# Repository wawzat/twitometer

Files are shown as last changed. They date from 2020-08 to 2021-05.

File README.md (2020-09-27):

# Twitometer  
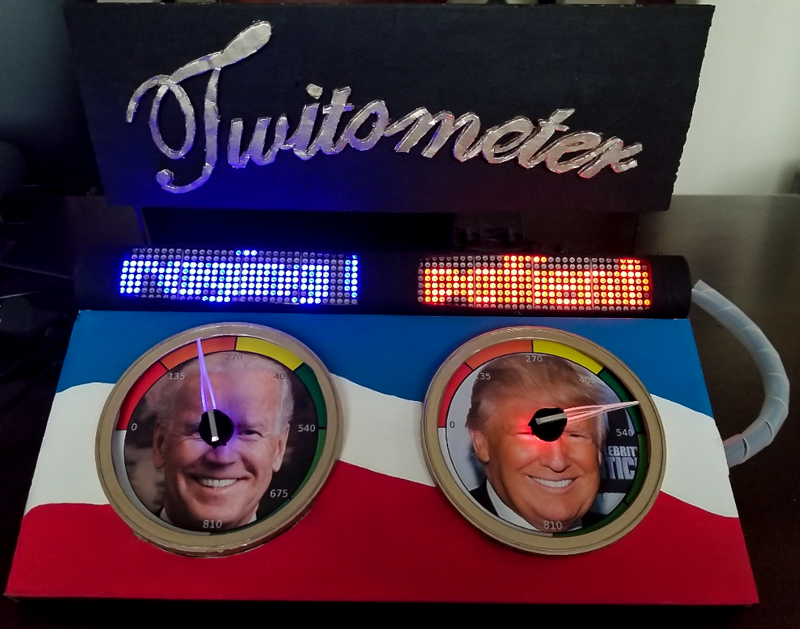
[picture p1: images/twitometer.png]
Twitometer


## Operation  
1. Displays Tweets and tweets per minute for US presidential candidates.
2. Raspberry Pi establishes a connection to Twitter Streaming API via Tweepy.  
3. Tweets are received that include text which matches a series of words ("Biden" "Trump").  
4. There are two Arduinos connected to the Pi via I2C. One for the LED Matrix displays and one for the two stepper motor gauges.
5. "Tweets per minute" is calculated and sent as bytes to the "stepper" Arduino via I2C.  
6. The Arduino then outputs a pulse for each microstep to a microstepping controller which is connected to two X27-168 instrumentation steppers which drive the gauge needles.  
7. Periodically the text of a tweet corresponding to a keyword (Biden or Trump) is sent to the "display" Arduino via I2C.  
8. The display Arduino sends the text over I2C to one of two corresponding MAX7219 8x32 LED matrices (blue for Biden, red for Trump).  
9. The corresponding tweet scrolls across each display.  

## Future improvements   
1. Attempt to classify tweets as "positive" or "negative" by comparison to lists of "positive" or "negative" words doesn't work very well. As a result, due to the nature of Twitter, the gauges might be best thought of as negative attention meters.   
2. Leftover unused variables and code fragments need to be cleaned up.  
3. I2C communications would benefit from more robust error checking and flow control. Periodic I2C errors exist.  
4. Scrolling text sometimes appears to be garbled or truncated.  
5. If too many I2C errors occur in succession, the Pi brute force reboots the Arduinos by cycling the power.  
6. Basic de-amateurization of the code.  

 ## Parts List
1. 1 x Raspberry Pi Model 3B+ w/ SD Card
2. 1 x USB power supply for Raspberry Pi
3. 2 x Arduino Pro Mini 5V/16Mhz
4. 1 x SparkFun DC/DC Converter Breakout (BOB-09370)
5. 1 x 1/2 Watt  1.3K ohm Carbon Comp Resistor
6. 1 x 1/2/4 SOP28 SSOP28 TSSOP28 to DIP28 0.7" Header Spacing SMD Adapter PCB Board
7. 1 x AX AX1201728SG SOP-28 Quad Microstepping Controller IC
8. 2 x X27-168 Stepper Motors
9. 1 x 2x uxcell Instrument Cluster Pointer Needle Set for HAVAL H2 (use small dia heat shrink on motor stems for friction fit)
10. 1 x DAOKI MAX7219 Dot led Matrix MCU 8x32 LED Display Module for Arduino, Blue
11. 1 x DAOKI MAX7219 Dot led Matrix MCU 8x32 LED Display Module for Arduino, Red
12. 1 x Red LED
13. 1 x 150 ohm resistor
14. 1 x Blue LED
15. 1 x 100 ohm resistor
16. Misc shrink tubing
17. Misc jumper wires
18. 1 x Adafruit Pi T-Cobbler Plus w/ ribbon cable
19. Spiral cable wrap
20. Coobl Dupont Jumper Wire Male Pin Connectors 2.54mm
21. 1 x BB400 Solderless Breadboard 
22. 1 x BB830 Solderless Breadboard

## Schematic Diagram  
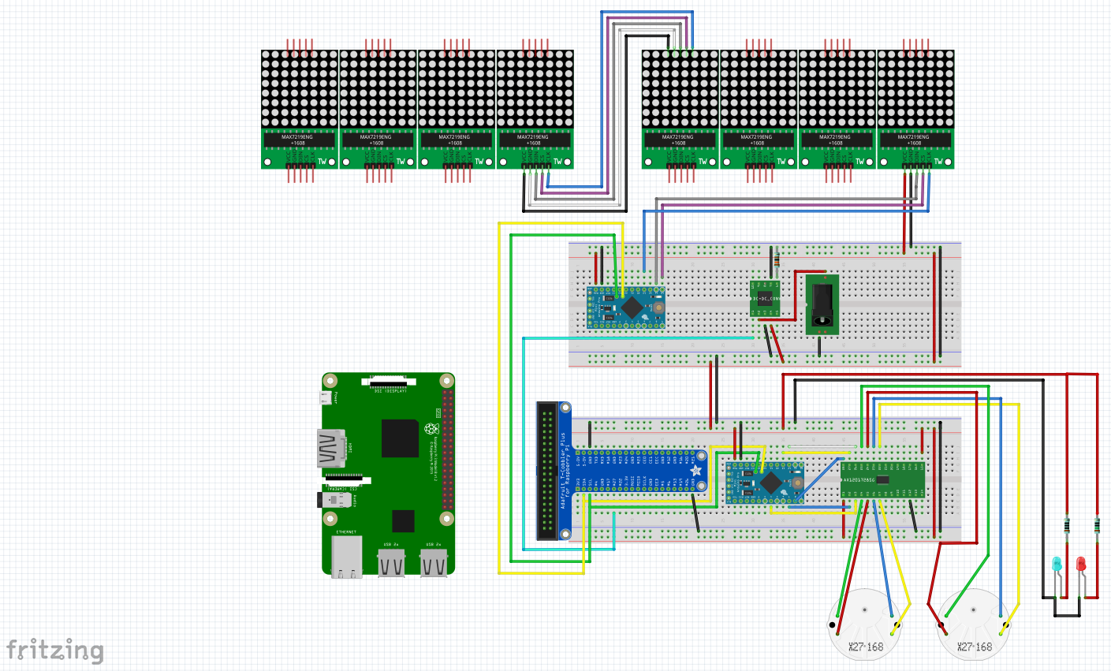
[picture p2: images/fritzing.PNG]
fritzing


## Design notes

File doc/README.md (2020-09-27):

Twitometer

Operation
Raspberry Pi establishes a Twitter Streaming API via Tweepy. 
Tweets are retrieved that include text that match a series of words (Biden Trump) 
"Tweets per minute" is calculated and sent to one of two Arduino's via I2C 
The Arduino outputs a pulse for each microstep to a microstepping controller which is connected to an X27-168 instrumentation stepper. 
Periodically  the text of a tweet corresponding to a keyword (Trump or Biden) is sent to the second Arduino via I2C. 
The second Arduino sends the text over I2C one of two corresponding MAX7219 8x32 LED matrices (blue for Biden, red for Trump). 
The corresponding tweet scrolls across each display. 

Future improvements
Naive attempt to classify tweets as "positive" or "negative" by comparison to lists of "positive" or "negative" words doesn't work very well. 
 
Left over unused variables and code fragments need to be cleaned up. 
 
I2C communications might benefit from more robust error checking and flow control. Periodic I2C errors still exist. 
 
Periodically scrolling text appears to be garbled or truncated.
 
If too many I2C errors occur in succession, the PI brute force reboots the Arduinos by cycling the power. 
 
Basic de-amateurization 

Schematic Diagram 
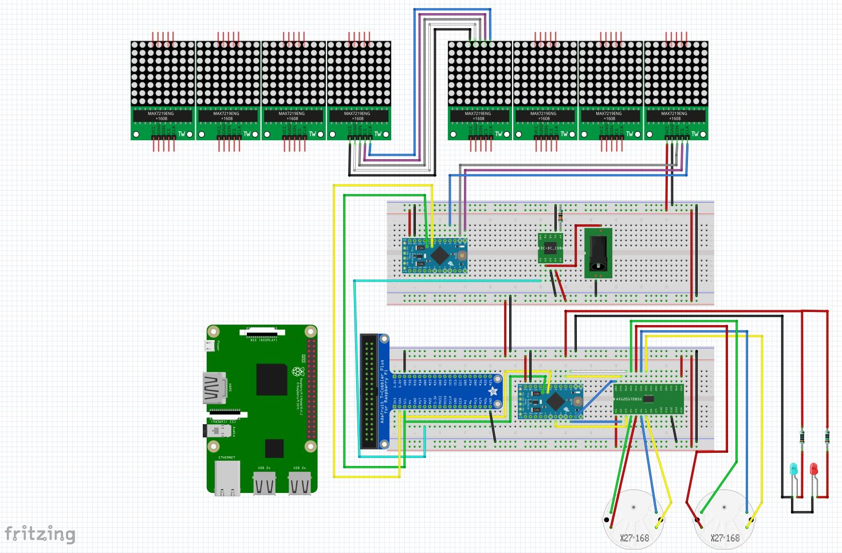
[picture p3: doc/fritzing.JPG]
fritzing


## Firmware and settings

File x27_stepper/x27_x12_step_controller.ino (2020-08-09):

//Receives bytes from Raspberry Pi in the format XYYYY where X is the motor number and YYYY is the desired motor position.
//YYYY is variable length from 1 to 3240 (270 Deg)
//James S. Lucas 20200726
#include <SwitecX12.h>
#include <Wire.h>
const int STEPS = 315 * 12;
const int A_STEP = 8;
const int A_DIR = 2;
const int B_STEP = 4;
const int B_DIR = 7;
const int RESET = 12;

SwitecX12 motor1(STEPS, A_STEP, A_DIR);
SwitecX12 motor2(STEPS, B_STEP, B_DIR);

//Arduino code to receive I2C communication from Raspberry Pi

// Define the I2C address of this device.
#define addr 0x08

void setup(void) {
  digitalWrite(RESET, HIGH);
  Serial.begin(9600);
  motor1.zero();
  motor2.zero();

  // begin running as an I2C slave on the specified address
  Wire.begin(addr);
 
  // create event for receiving data
  Wire.onReceive(receiveEvent);
}


//Global variables for position
int position1 = 0;
int position2 = 0;


// Function that executes whenever data is received from master
void receiveEvent(int howMany) {
  char cmd[16];
  char buffer[5];
  int motor_num;
  int char_pos = 0;
  while (Wire.available()) { // loop through all but the last
    char c = Wire.read(); // receive byte as a character
    cmd[char_pos] = (char)c;
    char_pos++;
    cmd[char_pos] = '\0';
  }
  char_pos = 0;


//Parse the command into motor number and position
  motor_num = cmd[0];
  buffer[0] = cmd[1];
  buffer[1] = cmd[2];
  buffer[2] = cmd[3];
  buffer[3] = cmd[4];
  buffer[4] = '\0';

  if (motor_num == 1) {
    position1 = atoi(buffer);
  }
  else if (motor_num == 2) {
    position2 = atoi(buffer);
  }
}


void loop(void) {
 
  motor1.setPosition(position1);
  motor2.setPosition(position2);

  motor1.update();
  motor2.update();
}

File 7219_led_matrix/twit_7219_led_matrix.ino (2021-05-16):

/* Example code for scrolling text effect on MAX7219 LED dot matrix display with Arduino. More info: https://www.makerguides.com */

// Include the required LED libraries:
#include <MD_Parola.h>
#include <MD_MAX72xx.h>
#include <SPI.h>

#include <Wire.h>

// Define hardware type, size, and output pins:
#define HARDWARE_TYPE MD_MAX72XX::FC16_HW
#define MAX_DEVICES 8
#define num_zones 2
#define CS_PIN 10

// Create a new instance of the MD_Parola class with hardware SPI connection:
MD_Parola myDisplay = MD_Parola(HARDWARE_TYPE, CS_PIN, MAX_DEVICES);

// Define the I2C address of this device for receiving data from Raspberry Pi
#define addr 0x06

char msg[290];
char msg_0[290];
char msg_1[290];
int char_pos = 0;
int block_count = 0;
int block_flag = 0;

void setup() {
  Serial.begin(9600);
  // begin running as an I2C slave on the specified address
  Wire.begin(addr);
 
  // create event for receiving data
  Wire.onReceive(receiveEvent);

  // Intialize the LED object:
  myDisplay.begin(num_zones);
  //myDisplay.begin();

  // Setup display zones
  myDisplay.setZone(0, 0, 3);
  myDisplay.setZone(1, 4, 7);
  
  // Set the intensity (brightness) of the display (0-15):
  myDisplay.setIntensity(0);
  // Clear the display:
  myDisplay.displayClear();
}


// Function that executes whenever data is received from master
void receiveEvent(int howMany) {
  int loop_overrun = 0;
  while (Wire.available()) {
    if (block_count == 0) {
      // First byte is cmd byte = 1 or 2. 2 means it is the last block in the message.
      block_flag = Wire.read();
      block_count++;
    }
    // from the second byte on
    else {
      char c = Wire.read();
      msg[char_pos] = (char)c;
      char_pos++;
      msg[char_pos] = '\0';
      if (char_pos >= 289) {
        char_pos = 0;
        //block_flag = 0;
        //block_count = 0;
        //msg[0] = '\0';
        //loop_overrun = 1;
        Serial.println("Loop Overrun");
      }
    }
    //if (loop_overrun == 1) {
      //loop_overrun = 0;
      //break;
    //}
  }
  if (block_flag == 3) {
    char display_num_char = msg[char_pos - 1];
    int display_num = display_num_char - '0';
    msg[char_pos - 1] = '\0';
    if (display_num == 0) {
      strcpy( msg_0, msg );
    }
    if (display_num == 1) {
      strcpy( msg_1, msg );
    }
    // Done receiving the last block in the message. Display it.
    char_pos = 0;
    Serial.println(display_num);
    Serial.println(msg);
    if (display_num == 0) {
      myDisplay.displayClear(0);
      myDisplay.displayZoneText(display_num, msg_0, PA_LEFT, 30, 0, PA_SCROLL_LEFT, PA_SCROLL_LEFT);
    }
    if (display_num == 1) {
      myDisplay.displayClear(1);
      myDisplay.displayZoneText(display_num, msg_1, PA_LEFT, 30, 0, PA_SCROLL_LEFT, PA_SCROLL_LEFT);
    }
    msg[0] = '\0';
  }
  block_count = 0;
  block_flag = 0;
}


void loop() {
  if (myDisplay.displayAnimate()) {
    myDisplay.displayReset();
  }
}

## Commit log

2020-06-14 Add stepper motor libraries
2020-06-14 Fixed current position
2020-06-14 Fixed another issue with current_position
    [twitometer.py]
2020-06-14 Hopefully last issue with current_position
    [twitometer.py]
2020-06-14 Fix issue with self.current_position
    [twitometer.py]
2020-06-14 Fixed issue with sentiment_rate
    [twitometer.py]
2020-06-14 Remove print
2020-06-14 Set tweepy stream filteer is_async=True to see if stepper driver blocking
2020-06-14 Stop stepper to see if blocking updates
2020-06-14 Change stepper value to pos_tweet_rate
2020-06-14 Change stepper scaling
2020-06-14 Disable stepper code for testing
2020-06-14 Disable stepper for test
2020-06-15 Print blank row before message for troubleshooting
2020-06-15 Revert to \r message print
    [twitometer.py]
2020-06-15 Convert motor libraries to Python3
2020-06-15 Re-enable motor code
2020-06-15 Change motor scale
2020-06-15 Add delay to motor update
2020-06-15 Change motor speed parameter
2020-06-15 Fix reversed gauge elapsed time calc
    [twitometer.py]
2020-06-15 Change step matrix per arduino driver code for x27
2020-06-15 Debug print step2coils
2020-06-15 Debug print
2020-06-15 Change currentstep
2020-06-15 Change motor speed to 50 RPM
2020-06-15 Change motor mode from double to single
2020-06-15 Remove debug print
2020-06-15 Fix error with self.Motors DCMotor not defined. Removed.
2020-06-16 Revert to original motor libarary for testing
    [twitometer.py]
2020-06-16 Try new custom stepper library again
2020-06-16 Debug print statements
2020-06-16 Added PWM code back in to see if that is the problem
2020-06-16 Add self.motors... to Raspi_MotorHat class
2020-06-18 Changed motor driver board to Adafruit Bonnet
2020-06-18 Fixed error with stepper position
    [twitometer.py]
2020-06-18 Fix issue with number of steps to take
    [twitometer.py]
2020-06-18 Fix typo kit.stepper1.release()
2020-06-18 Added second stepper
2020-06-18 Fixed issue with dict_sentiment
    [twitometer.py]
2020-06-18 Fix issue with current_position_1 and 2
    [twitometer.py]
2020-06-18 Track last gauge time_1 and 2
2020-06-18 Fix isssue with gauge elapsed time
    [twitometer.py]
2020-06-20 Fix minor indentation issues
    [twitometer.py]
2020-06-20 Filter for RT
2020-06-20 Fixed error with self.last_update_time
    [twitometer.py]
2020-06-20 Added tpm_num_tweets for correct instantaneous TPM
    [twitometer.py]
2020-06-20 Correct for negative tpm
    [twitometer.py]
2020-06-20 Increase tpm calc delay to 5 seconds, decrease stepper step to .005 sec
2020-06-20 make mystream.filter async
2020-06-20 Swap candidate motors
2020-06-22 Fix issue with TPM methodology
    [twitometer.py]
2020-06-22 CHange TPM and motor delays
2020-06-28 Start adding multi motor functionality
2020-06-28 Add second indicator stepper
2020-06-28 Fix issue with gauge update frequency
    [twitometer.py]
2020-07-03 Remove obsolete stepper driver code
2020-07-03 Zero motors on ctrl-c exit
2020-07-03 Resolve div 0 error. Delete sleep in ctrl-c exception handler
    [twitometer.py]
2020-07-04 add os.system("stty echo" to atexit function to try to avoid garbled terminal
    [twitometer.py]
2020-07-04 Remove with block didn't seem to work. Exited right away
    [twitometer.py]
2020-07-04 add sleep(1) to __init__ to avoid div 0 due to 0 ET
    [twitometer.py]
2020-07-05 Removed all but absolutely necessary calcs from on_status() trying to eliminate incomplete twitter read errors
    [twitometer.py]
2020-07-05 Fix elapsed_time to elapsed_time.seconds
    [twitometer.py]
2020-07-05 Only write to terminal every second to see if that helps with twitter receive error
    [twitometer.py]
2020-07-05 Change fast indicator calc to microseconds to avoid div 0
    [twitometer.py]
2020-07-05 Fast indicator try milliseconds
2020-07-06 Change I2C write error message
    [twitometer.py]
2020-07-06 move_stepper_x() track motor_1 and motor_2 et separate;y
2020-07-06 Fixed missing comma in move_stepper call
    [twitometer.py]
2020-07-10 Remove debut print
2020-07-11 Increase tpm reset to 20 sec
    [twitometer.py]
2020-07-12 Reduce tpm reset from 20 to 6 sec and reduce smooth readings to 6
    [twitometer.py]
2020-07-12 Increase tpm reset to 8 sec and smoothing count to 40
    [twitometer.py]
2020-07-13 Add LED matrix
2020-07-13 Fix indent in import section
    [twitometer.py]
2020-07-16 Comment out LED matrix write as it is blocking
2020-07-18 Add second Arduino for LED Matrix display
2020-07-18 Turncate LED matrix bytes to 32 bits for now
2020-07-18 Try a differnt way of truncating bytes to LED matrix
2020-07-18 Try a short test msg to LED matrix
    [twitometer.py]
2020-07-19 Try to send acutal Tweet to led matrix
2020-07-19 Reduce led update frequency to 30 sec and biden only
2020-07-19 Fix indent. return in write_matrix()
    [twitometer.py]
2020-07-20 Issue trying to interate over int. Added range(int)
    [twitometer.py]
2020-07-20 Correct issue with trying to concatenate string to list
    [twitometer.py]
2020-07-20 write_matrix move led_write_time assignment to top
2020-07-20 write_matrix set led_write_time on except
2020-07-20 write_matrix() pass in led_write_time and change != calc for 0 indexed range
2020-07-20 I2C error message now reference which function
    [twitometer.py]
2020-07-22 write_matrix change to use cmd byte for I2C flow control
2020-07-22 write_matrix() fix first loop range
    [twitometer.py]
2020-07-23 Increase time between led matrix tweet updates to 40 sec
2020-07-23 Now writes to two led displays
2020-07-23 Put led write code under each candidate
2020-07-23 Independently track led write times
2020-07-23 Move led write code up a level
2020-07-24 Change led update frequency to 38 + random 1-4 sec
2020-07-25 Add Arduino code to repository
2020-07-25 Add Arduino code
2020-07-25 Removed old Arduino files from repo
2020-07-26 Modify move_stepper() to use I2C cmd byte to select motor_num
2020-07-26 move_stepper() motor_num to 0x0# format
2020-07-26 write_data() test hard code cmd 0x01 to test I2C errors
    [twitometer.py]
2020-07-26 Disable writing to LED to test stepper I2C
2020-07-26 Re-enable LED writing
2020-07-26 Dispabe stepper write to test led I2C
2020-07-26 Re-enable stepper writes
2020-07-27 Swap led numbers 0 = right, 1 = left
    [twitometer.py]
2020-07-27 Increase led update to 45 sec + randint 10
2020-07-27 writeData() print exception to try to pin down I2C errors
    [twitometer.py]
2020-07-27 write_data() stop printing exception
2020-08-02 Stop debug print
2020-08-08 Added control of power supply on / off
2020-08-08 correct exit code, specific elif trump
    [twitometer.py]
2020-08-08 add i2c error function
    [twitometer.py]
2020-08-08 deboug print
2020-08-08 Correct reversed eta calc, add delay after exit move stepper
    [twitometer.py]
2020-08-09 Add sleep to i2c_error_tracker and change durations
2020-08-09 eliminate sentiment_pct calc. Keep getting tweepy io errors. Taking too long to process
    [twitometer.py]
2020-08-09 Add i2c_error_tracker call to write_matrix too
2020-08-09 Turn Tweepy is_async back on due to io errors
    [twitometer.py]
2020-08-09 Increase delay after i2c_error power restored
2020-08-09 replace new lines with spaces in displayed tweets
    [twitometer.py]
2020-08-23 Change delays in error tracker and exit functions
    [twitometer.py]
2020-08-30 Increase inital Arduino after power up delay from 2 to 4 seconds
2020-09-27 Insert Fritzing
2020-09-27 Add Fritzing file
    [twitometer.fzz]
2020-09-27 Minor revisions
    [twitometer.fzz]
